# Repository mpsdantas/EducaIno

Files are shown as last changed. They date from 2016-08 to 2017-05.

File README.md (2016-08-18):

EducaIno - Simplificando a Robótica                   
===================
Logo EducaIno

A placa EducaIno (Educação + Arduino) é um projeto de uma placa de circuito impresso open source que está sendo desenvolvido no Laboratório de Automação e Robótica da [Universidade Federal do Rio Grande do Norte](https://sistemas.ufrn.br/portal/PT/). Atualmente o projeto conta com alguns desenvolvedores sendo os mais ativos o Professor Doutor [Orivaldo Vieira De Santana Junior](https://sigaa.ufrn.br/sigaa/public/docente/portal.jsf?siape=1943220) e [Marcus Paulo Soares Dantas](http://marcuspaulo.esy.es/) Graduando do curso de Ciências e Tecnologia - Engenharia da Computação.

----------
Versões do EducaIno
-------------
**EducaIno 1.0**
</br>
</br>


Resultados de testes de uso:  ***REPROVADO**       ícone de reprovação
</br>
</br>
**EducaIno 1.1**
</br>
</br>

</br>
</br>
Resultados de testes de uso:  ***EM ANALISE** 

----------
Registro de melhorias
-------------
1.0 -> 1.1

 - Correção da ligação do pino de 5v incorreta, anteriormente conectado ao GND.
 - Dois conectores de sensores conectados corretamente a pinos de dados.
 - Pinos enable do l293D agora são ligados a pinos de dados.

----------

Universidade Federal do Rio Grande do Norte
-------------
A Universidade Federal do Rio Grande do Norte (UFRN) é uma instituição de ensino superior pública brasileira, com sede na cidade de Natal, no estado do Rio Grande do Norte. É a principal universidade do estado e uma das dez maiores universidades federais do Brasil em número de alunos de graduação matriculados. De acordo com o Índice Geral de Cursos, é a universidade mais bem avaliada no Rio Grande do Norte e das regiões Norte e Nordeste, com um total de 82,64 pontos, estando na 11ª posição entre as instituições de nível superior nacionais.
> **[Mais Informações sobre a UFRN](https://pt.wikipedia.org/wiki/Universidade_Federal_do_Rio_Grande_do_Norte)**

----------

EducaIno: Um robô por aluno
-------------------
<center>Um robô por aluno</center>
</br>
O URA (Um robô por aluno) é um projeto dos pesquisadores do Laboratório NatalNet da Universidade Federal do Rio Grande do Norte (UFRN), que têm o objetivo de utilizar a robótica educacional para difundir o interesse por tecnologia em todos os níveis de ensino no País. 
Tendo em vista o potencial do projeto URA a placa EducaIno está sendo desenvolvida como uma forma de melhoria para esse projeto criando uma placa mais agradável e de fácil utilização para os alunos.
> **[Mais Informações sobre o URA](http://www.natalnet.br/ura/)**

----------

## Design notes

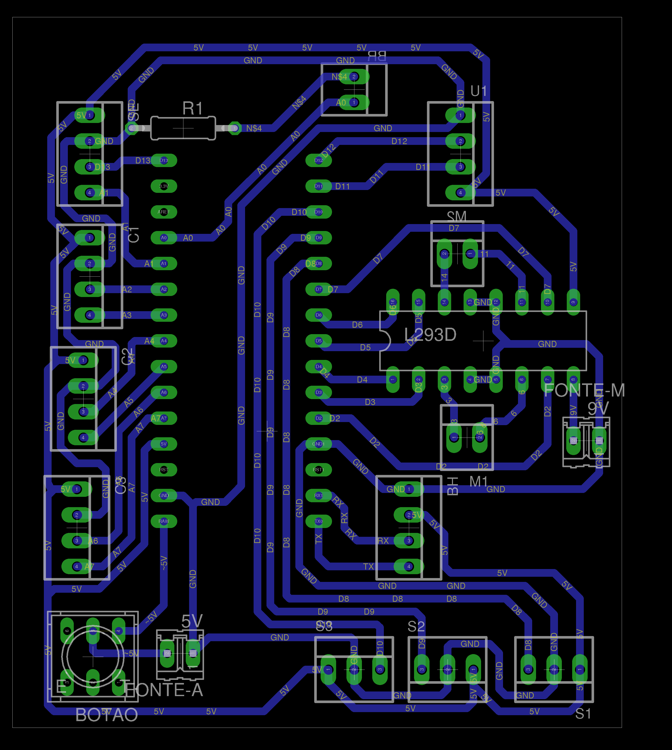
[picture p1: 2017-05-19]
EducaInoV2.0/pcb.png

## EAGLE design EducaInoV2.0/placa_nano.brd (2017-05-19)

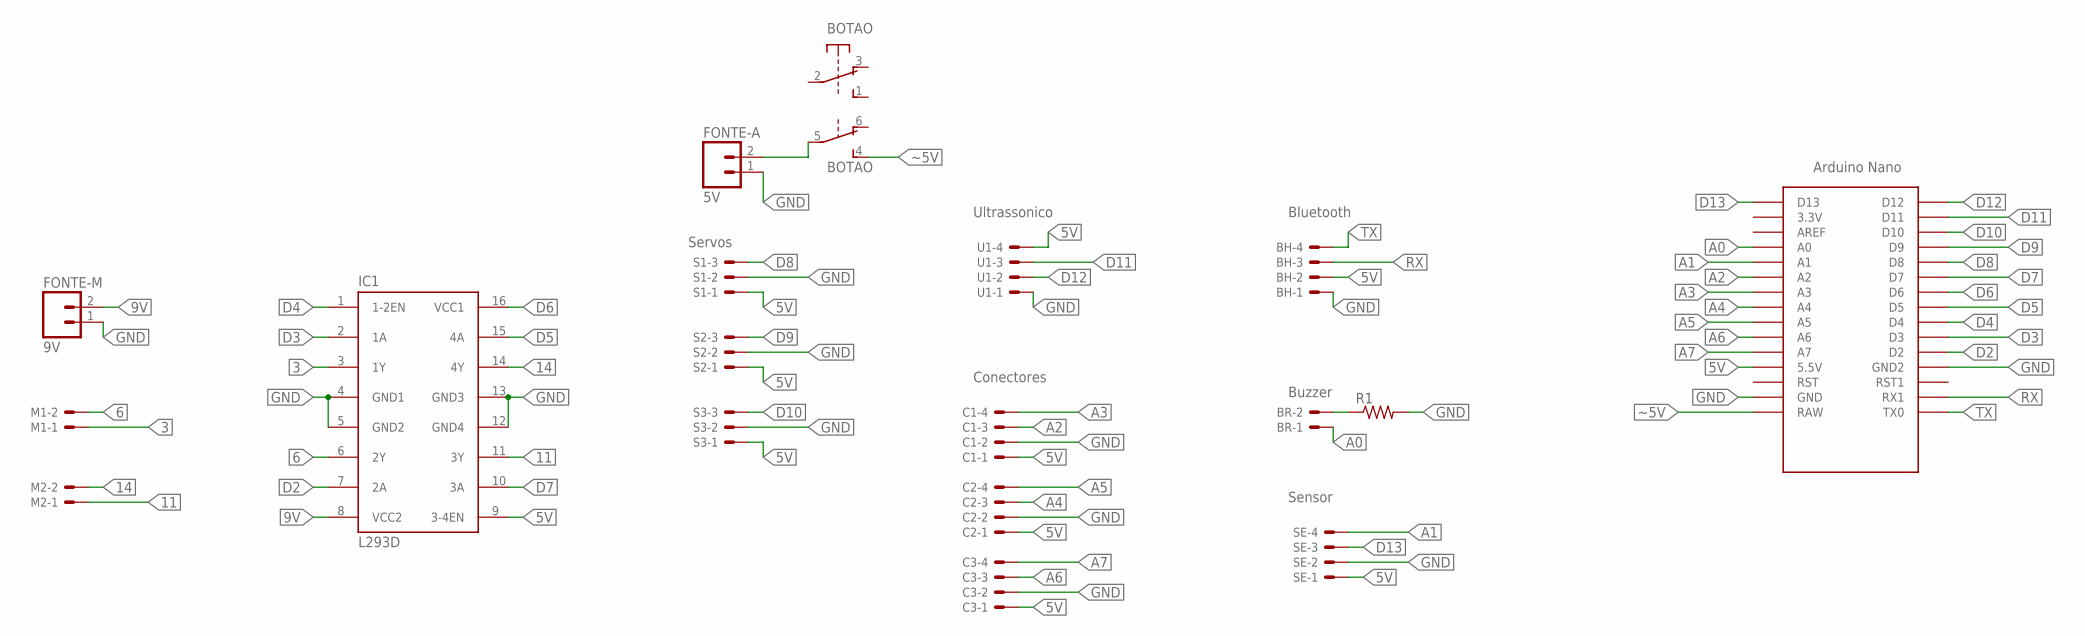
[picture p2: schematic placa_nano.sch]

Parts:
BH: 22-23-2041
BOTAO: 9077-2
BR: 22-23-2021
C1, C2, C3: 22-23-2041
FONTE-A: 5V; 02P
FONTE-M: 9V; 02P
IC1: L293D; DIL16
M1, M2: 22-23-2021
R1: R-US_0207/10; 0207/10
S1, S2, S3: 22-23-2031
SE: 22-23-2041
U1: 22-23-2041
U$1: NANO

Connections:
3: IC1.3 (1Y), M1.1
5V: BH.2, C1.1, C2.1, C3.1, IC1.9 (3-4EN), S1.1, S2.1, S3.1, SE.1, U1.4, U$1.5V (5.5V)
6: IC1.6 (2Y), M1.2
9V: FONTE-M.2, IC1.8 (VCC2)
11: IC1.11 (3Y), M2.1
14: IC1.14 (4Y), M2.2
A0: BR.1, U$1.A0
A1: SE.4, U$1.A1
A2: C1.3, U$1.A2
A3: C1.4, U$1.A3
A4: C2.3, U$1.A4
A5: C2.4, U$1.A5
A6: C3.3, U$1.A6
A7: C3.4, U$1.A7
D2: IC1.7 (2A), U$1.D2
D3: IC1.2 (1A), U$1.D3
D4: IC1.1 (1-2EN), U$1.D4
D5: IC1.15 (4A), U$1.D5
D6: IC1.16 (VCC1), U$1.D6
D7: IC1.10 (3A), U$1.D7
D8: S1.3, U$1.D8
D9: S2.3, U$1.D9
D10: S3.3, U$1.D10
D11: U1.3, U$1.D11
D12: U1.2, U$1.D12
D13: SE.3, U$1.D13
GND: BH.1, C1.2, C2.2, C3.2, FONTE-A.1, FONTE-M.1, IC1.4 (GND1), IC1.5 (GND2), IC1.12 (GND4), IC1.13 (GND3), R1.2, S1.2, S2.2, S3.2, SE.2, U1.1, U$1.GND, U$1.GND1 (GND2)
unnamed: BR.2, R1.1
RX: BH.3, U$1.RX1
TX: BH.4, U$1.TX0
~5V: BOTAO.4 (S), BOTAO.5, FONTE-A.2, U$1.RAW

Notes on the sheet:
Servos
Ultrassonico
Bluetooth
Buzzer
Sensor
Conectores

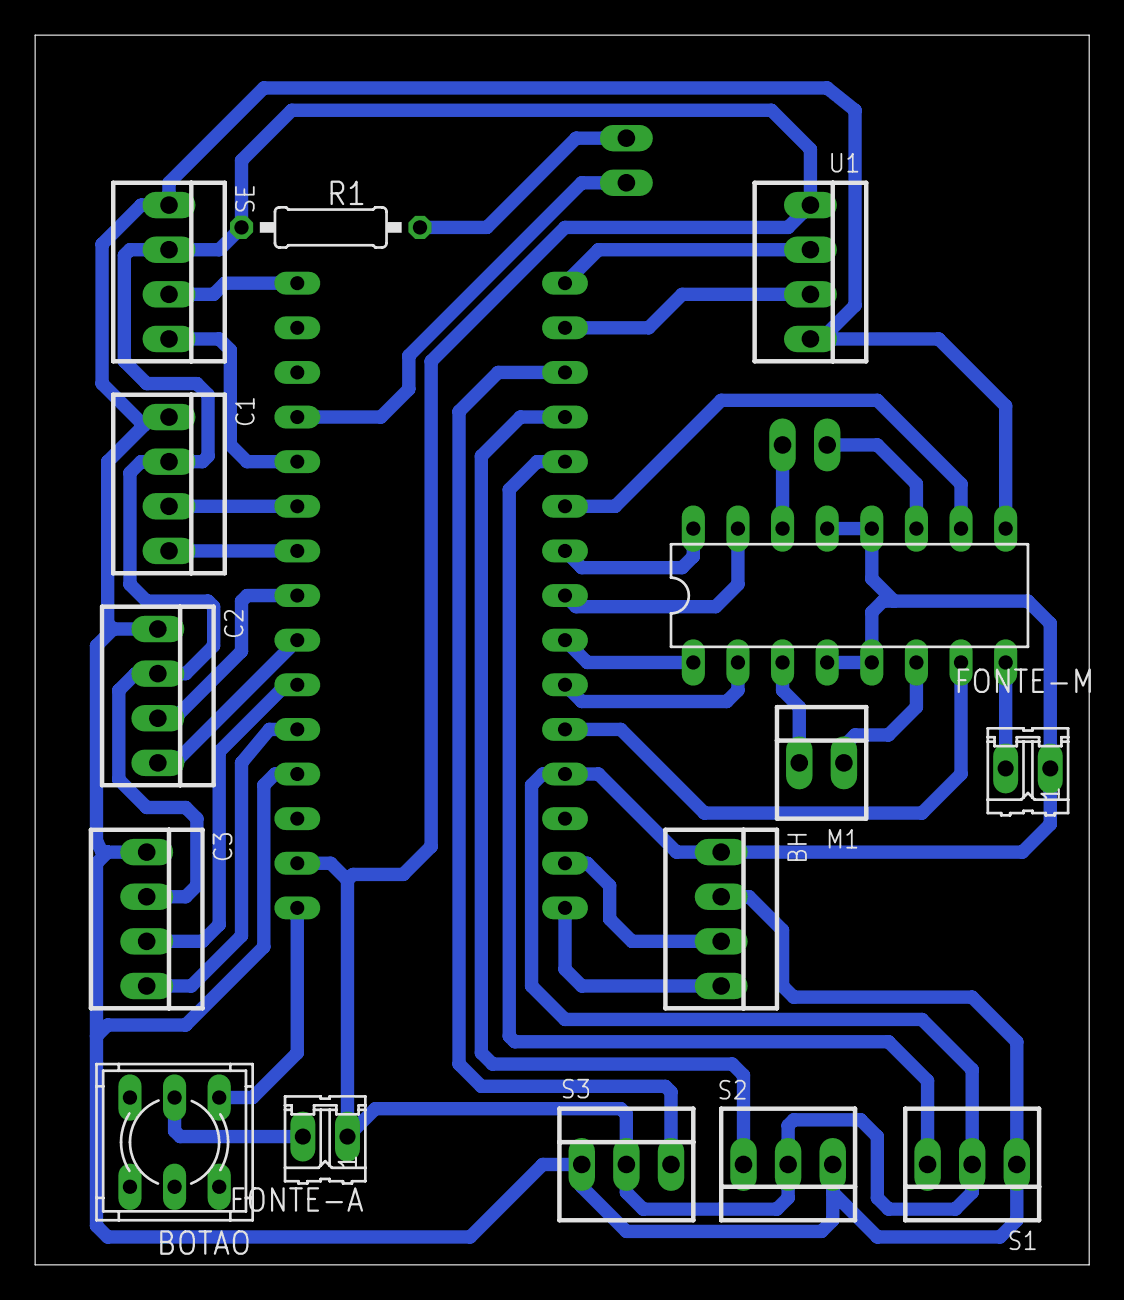
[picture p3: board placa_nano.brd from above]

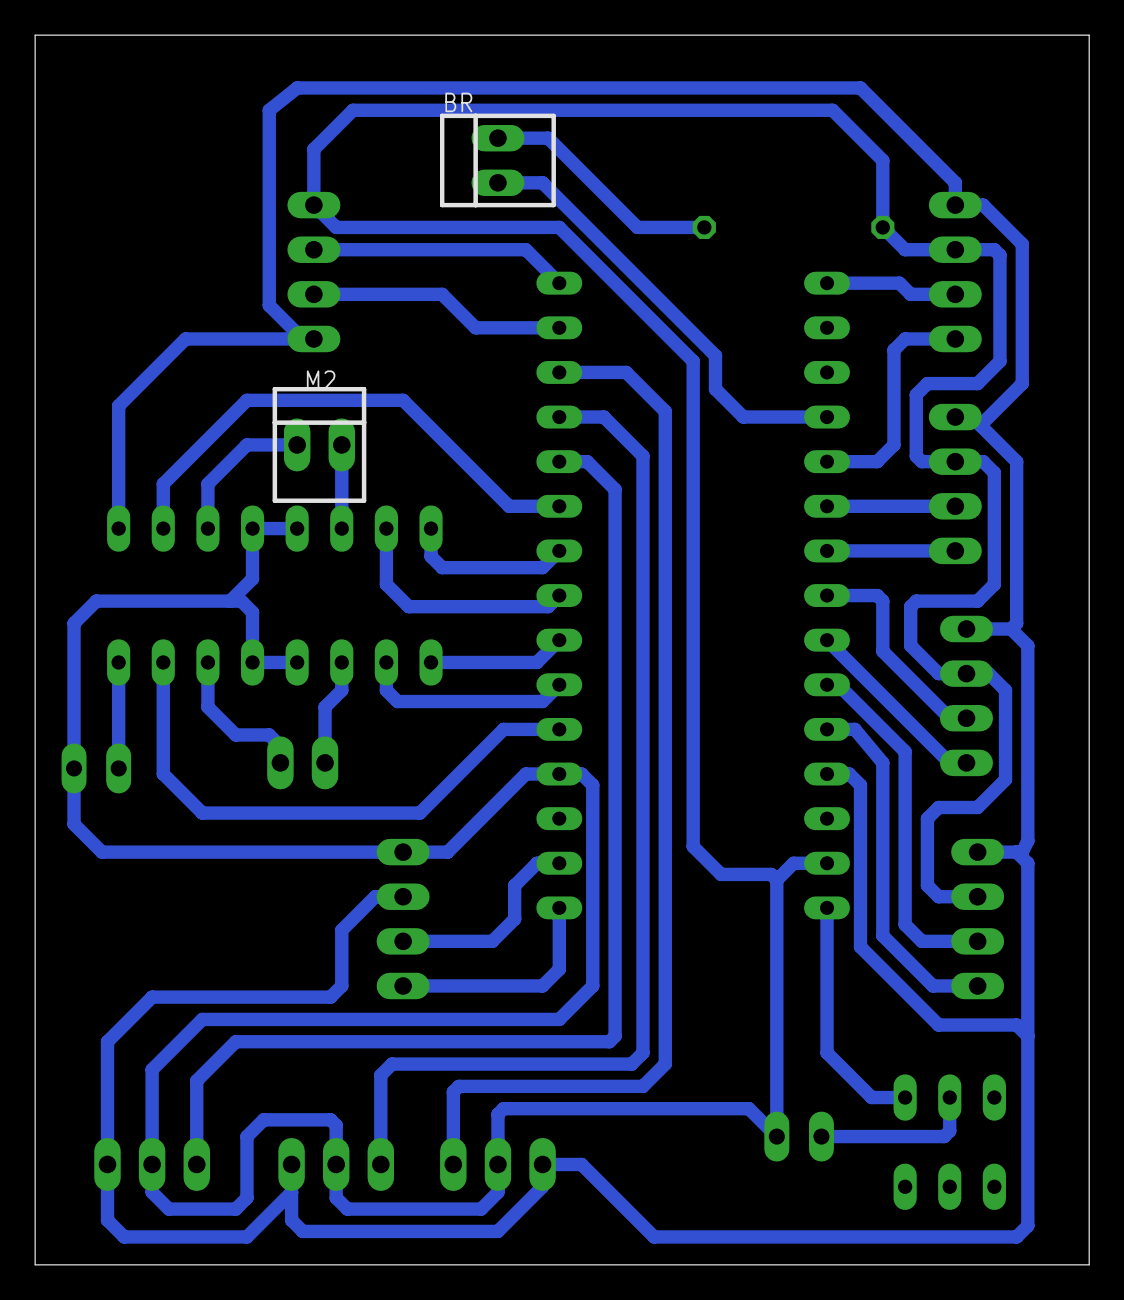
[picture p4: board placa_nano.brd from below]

Board: 2 copper layers, 60.0 x 70.0 mm, 18 parts (2 on the bottom side), 31 nets.

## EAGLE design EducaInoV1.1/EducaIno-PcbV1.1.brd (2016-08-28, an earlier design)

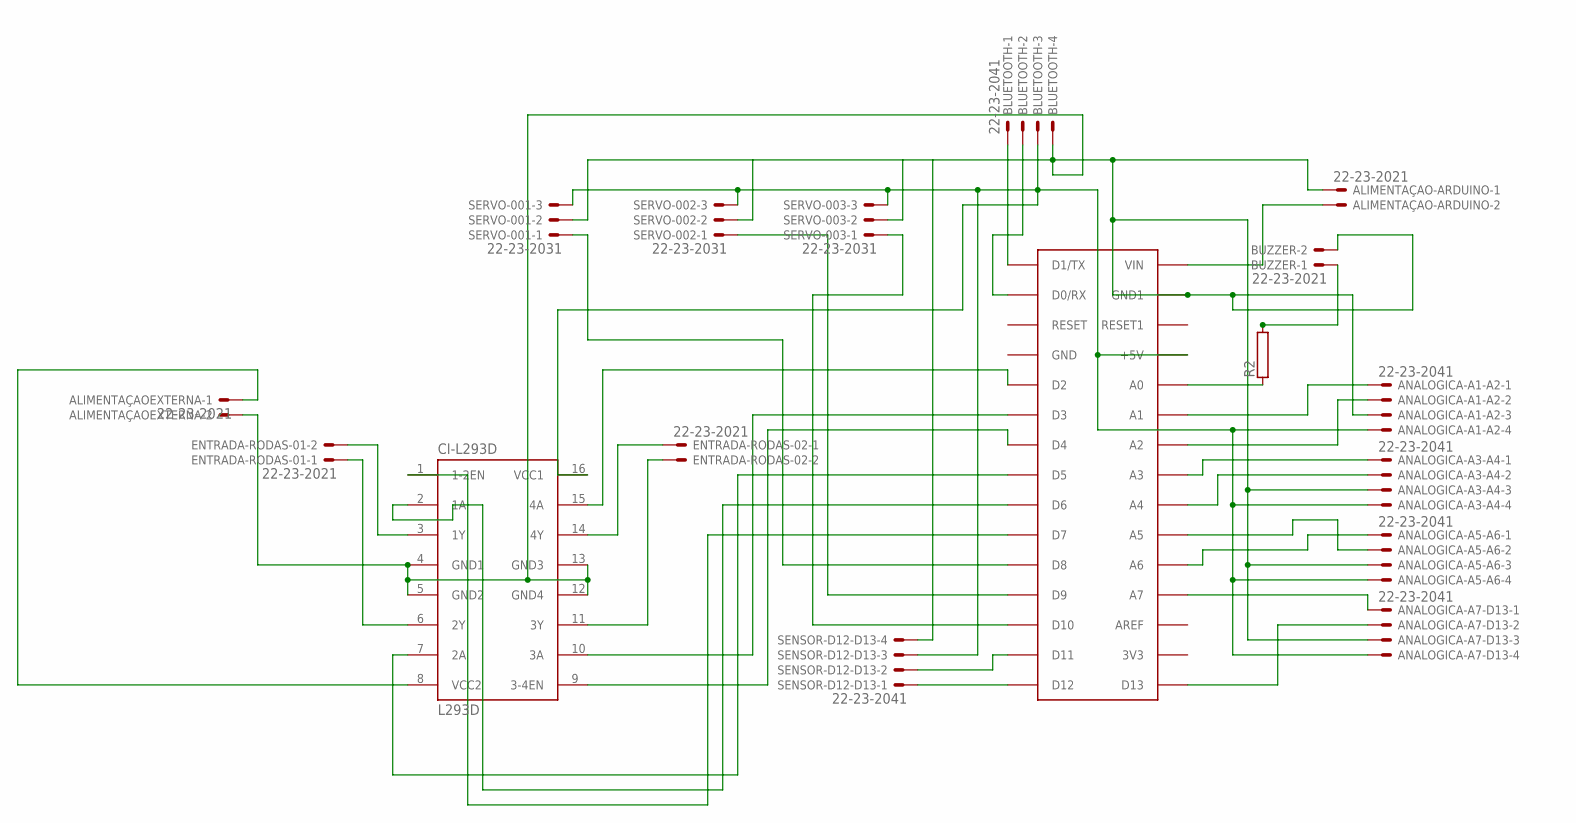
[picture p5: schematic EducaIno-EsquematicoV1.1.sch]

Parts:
ALIMENTAÇAO-ARDUINO: 22-23-2021
ALIMENTAÇAOEXTERNA: 22-23-2021
ANALOGICA-A1-A2, ANALOGICA-A3-A4, ANALOGICA-A5-A6, ANALOGICA-A7-D13: 22-23-2041
BLUETOOTH: 22-23-2041
BUZZER: 22-23-2021
CI-L293D: L293D; DIL16
ENTRADA-RODAS-01, ENTRADA-RODAS-02: 22-23-2021
R2: RHPS58; HPS58
SENSOR-D12-D13: 22-23-2041
SERVO-001, SERVO-002, SERVO-003: 22-23-2031
U$1: ARDUINONANO; PDIP-32

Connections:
unnamed: CI-L293D.1 (1-2EN), U$1.D7
unnamed: CI-L293D.3 (1Y), ENTRADA-RODAS-01.2
unnamed: ALIMENTAÇAO-ARDUINO.1, ALIMENTAÇAOEXTERNA.2, ANALOGICA-A1-A2.3, ANALOGICA-A3-A4.3, ANALOGICA-A5-A6.3, ANALOGICA-A7-D13.3, BLUETOOTH.4, BUZZER.2, CI-L293D.4 (GND1), CI-L293D.5 (GND2), CI-L293D.12 (GND4), CI-L293D.13 (GND3), SENSOR-D12-D13.4, SERVO-001.2, SERVO-002.2, SERVO-003.2, U$1.GND1
unnamed: ALIMENTAÇAOEXTERNA.1, CI-L293D.8 (VCC2)
unnamed: CI-L293D.6 (2Y), ENTRADA-RODAS-01.1
unnamed: CI-L293D.14 (4Y), ENTRADA-RODAS-02.1
unnamed: CI-L293D.11 (3Y), ENTRADA-RODAS-02.2
unnamed: CI-L293D.2 (1A), U$1.D6
unnamed: CI-L293D.7 (2A), U$1.D5
unnamed: CI-L293D.15 (4A), U$1.D2
unnamed: CI-L293D.10 (3A), U$1.D3
unnamed: CI-L293D.9 (3-4EN), U$1.D4
unnamed: SERVO-001.1, U$1.D8
unnamed: SERVO-002.1, U$1.D9
unnamed: SERVO-003.1, U$1.D10
unnamed: ALIMENTAÇAO-ARDUINO.2, U$1.VIN
unnamed: BUZZER.1, R2.2
unnamed: R2.1, U$1.A0
unnamed: ANALOGICA-A1-A2.1, U$1.A1
unnamed: ANALOGICA-A1-A2.2, U$1.A2
unnamed: ANALOGICA-A3-A4.1, U$1.A3
unnamed: ANALOGICA-A3-A4.2, U$1.A4
unnamed: ANALOGICA-A5-A6.2, U$1.A5
unnamed: ANALOGICA-A5-A6.1, U$1.A6
unnamed: ANALOGICA-A7-D13.1, U$1.A7
unnamed: ANALOGICA-A7-D13.2, U$1.D13
unnamed: BLUETOOTH.1, U$1.D1/TX
unnamed: BLUETOOTH.2, U$1.D0/RX
S$1: U$1.GND
S$3: SENSOR-D12-D13.2, U$1.D11
S$4: SENSOR-D12-D13.1, U$1.D12

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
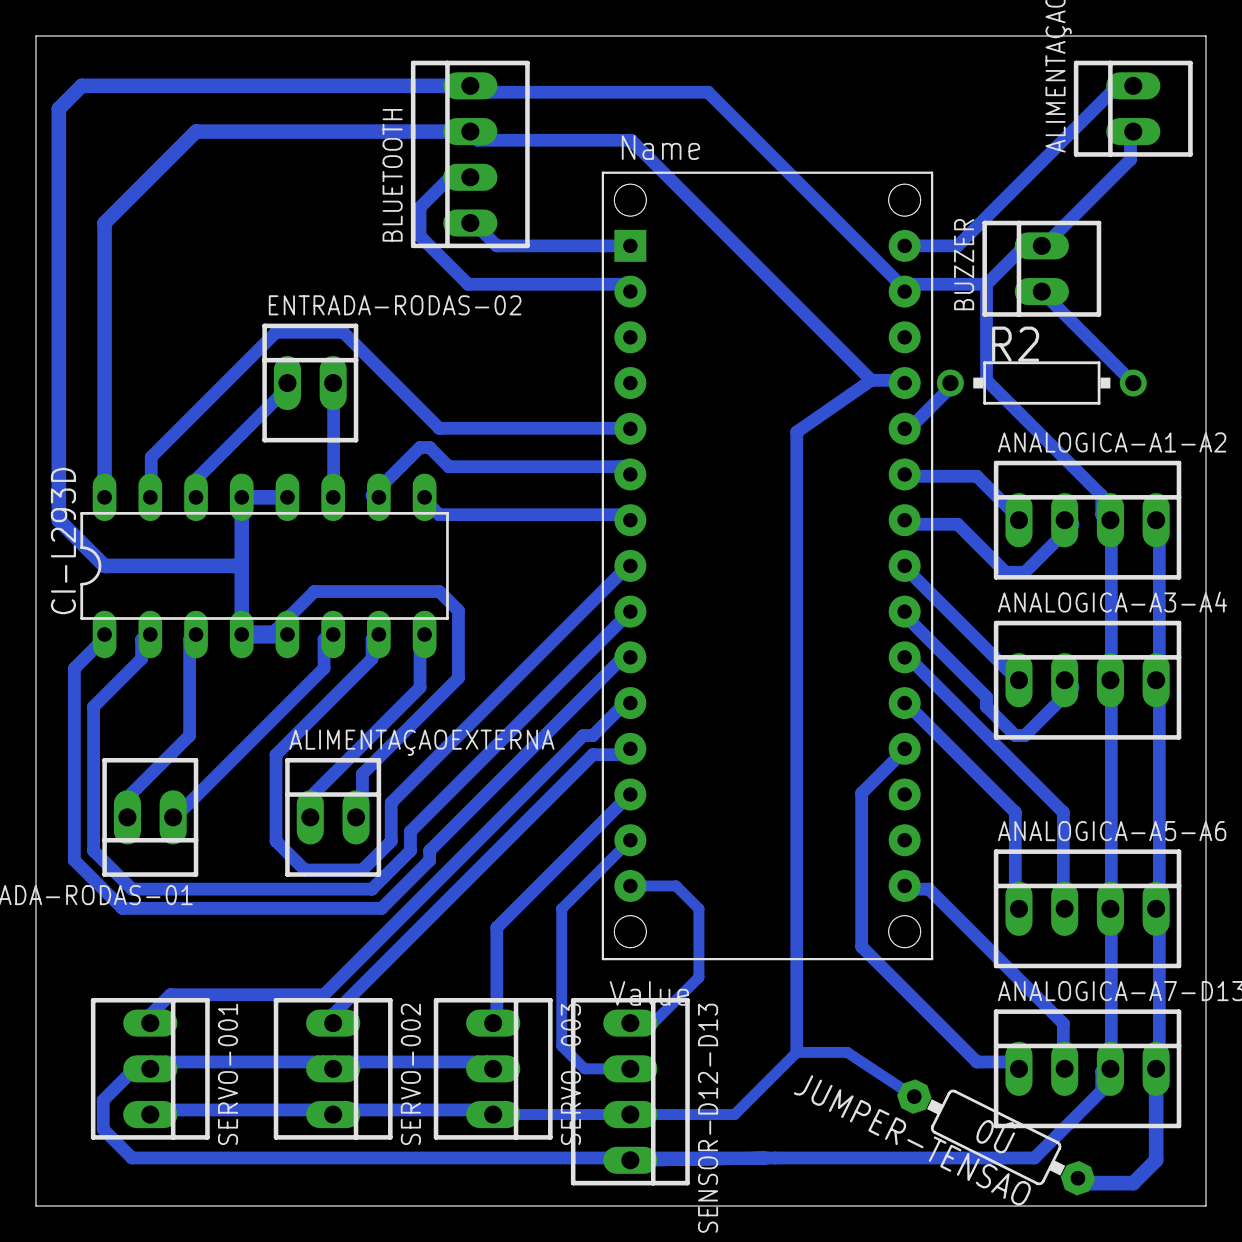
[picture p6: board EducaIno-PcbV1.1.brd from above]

Board: 2 copper layers, 65.0 x 65.0 mm, 18 parts (0 on the bottom side), 32 nets.

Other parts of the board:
JUMPER-TENSAO: 0R/10E

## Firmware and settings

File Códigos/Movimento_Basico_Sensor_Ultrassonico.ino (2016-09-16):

int echoPin = 11, trigPin = 12;
//Pino 11 recebe o pulso do echo  
//Pino 12 envia o pulso para gerar o echo 
void setup() {
  Serial.begin(9600); //inicia a porta serial
  pinMode(2,OUTPUT); //Definindo o pino 2 como saida de dados(ENABLE) RODAS 2.
  pinMode(3,OUTPUT); //Definindo o pino 3 como saida de dados Rodas1A.
  pinMode(4,OUTPUT); //Definindo o pino 4 como saida de dados Rodas1B.
  pinMode(5,OUTPUT); //Definindo o pino 6 como saida de dados Roda2A.
  pinMode(6,OUTPUT); //Definindo o pino 6 como saida de dados Roda2B.
  pinMode(7,OUTPUT); //Definindo o pino 7 como saida de dados(ENABLE) RODAS 1.
  //ATIVANDO ENABLE DAS RODAS
  digitalWrite(4,HIGH);
  digitalWrite(7,HIGH);
  //ATIVANDO ENABLE DAS RODAS
  pinMode(echoPin, INPUT); // define o pino 11 como entrada (recebe)  
  pinMode(trigPin, OUTPUT); // define o pino 12 como saida (envia) 
}
void loop() {
    frente();
    if(ultrassonico(echoPin, trigPin) < 10){
      tras();
      delay(500);
      direita();
      delay(500);
    }
}
int ultrassonico(int echoPin, int trigPin){
  //seta o pino 12 com um pulso baixo "LOW" ou desligado ou ainda 0  
    digitalWrite(trigPin, LOW);  
  // delay de 2 microssegundos  
    delayMicroseconds(2);  
  //seta o pino 12 com pulso alto "HIGH" ou ligado ou ainda 1  
    digitalWrite(trigPin, HIGH);  
  //delay de 10 microssegundos  
    delayMicroseconds(10);  
  //seta o pino 12 com pulso baixo novamente  
    digitalWrite(trigPin, LOW);  
  //pulseInt lê o tempo entre a chamada e o pino entrar em high  
    long duration = pulseIn(echoPin,HIGH);  
  //Esse calculo é baseado em s = v . t, lembrando que o tempo vem dobrado  
  //porque é o tempo de ida e volta do ultrassom  
    long distancia = duration /29 / 2 ;  
    return distancia;
}
void parar(){
  digitalWrite(2,LOW);
  digitalWrite(3,LOW);
  digitalWrite(5,LOW);
  digitalWrite(6,LOW);
}
void frente(){
  digitalWrite(2,HIGH);
  digitalWrite(3,LOW);
  digitalWrite(5,HIGH);
  digitalWrite(6,LOW);
}
void tras(){
  digitalWrite(2,LOW);
  digitalWrite(3,HIGH);
  digitalWrite(5,LOW);
  digitalWrite(6,HIGH);
}
void esquerda(){
  digitalWrite(2,LOW);
  digitalWrite(3,HIGH);
  digitalWrite(5,HIGH);
  digitalWrite(6,LOW);
}
void direita(){
  digitalWrite(2,HIGH);
  digitalWrite(3,LOW);
  digitalWrite(5,LOW);
  digitalWrite(6,HIGH);
}

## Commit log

2016-08-08 Placa funcional EducaIno versão 01
    [educacional_v7.fzz]
2016-08-08 Alteração de nomeclatura dos arquivos e criação de vizualização em png da placa.
    [EducaInoV1.fzz]
2016-08-15 Placa nova criada no eagle.
    [esquematico-educaino-V2.sch]
2016-08-15 Motivo de parada de utilização do fritzing
2016-08-15 Modificação de nome das pastas do EducaIno.
    [EducaInoV1.fzz, esquematico-educaino-V2.sch]
2016-08-17 Servos adicionados
    [esquematico-educaino-V2.sch]
2016-08-17 Adicionados componentes que faltavam (bluetooth e slots para outros sensores), o esquematico foi finalizado
    [esquematico-educaino-V2.sch]
2016-08-17 Adicionado figura para visualizar o esquematico
2016-08-17 Esquematico Final.
    [esquematico-educaino.sch]
2016-08-17 Esquematico final da placa V2
    [EDUCAINO-ESQUEMATICO.sch, EDUCAINO-PCB.brd, esquematico-educaino-V2.sch]
2016-08-17 Imagem adicionada da pcb da placa.
2016-08-18 Atualização de esquema de pastas
    [EducaIno-EsquematicoV1.1.sch, EducaIno-PcbV1.1.brd, EducaInoV0.9.fzz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]
2016-08-18 Correção de terra do pino l293d que não estava conectado corretamente.
    [EducaIno-PcbV1.1.brd]
2016-08-18 Correção de trilha do terra para exibição
2016-08-18 Pcb placa v1.1
2016-08-28 Modificação de pinos modu para conexão do cabo usb
    [EducaIno-PcbV1.1.brd]
2016-09-16 Código de movimentação simples para robô com sensor ultrassônico.
2017-05-19 Placa versão 2.0
    [placa_nano.brd, placa_nano.sch]
